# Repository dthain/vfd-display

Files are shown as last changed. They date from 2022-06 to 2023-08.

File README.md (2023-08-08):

# VFD Display Project

Some notes on building a display driver for a Futaba 16-LY-01ZL alphanumeric display.
It seems that Futaba no longer manufactures or supports these devices, but they are
commonly available for secondhand purchase.  The device has 37 pins at 0.2in spacing.

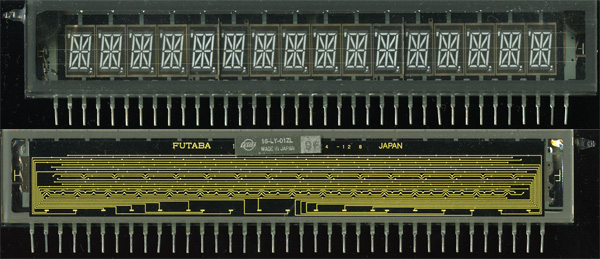
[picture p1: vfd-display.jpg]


This is a vacuum flourescent display (VFD), which is a variant of the vacuum tube.
A small AC current is used to heat a filament (cathode) when then produces electrons
via thermionic emission.  The electrons are naturally attracted to anodes, if they
are positively charged.  Each anode is coated with a flourescent material, and glows
a distinctive amber/green color when active.  Between the cathode and anode is a grid
that controls whether the electrons flow.

This particular one is a sixteen digit alphanumeric display.  Each digit has sixteen
segments, plus three more indicators: a dot in the upper left corner (Q) and
a decimal (R) and comma (S) in the lower right corner.  Each segment corresponds
to one anode, and each digit is controlled by a separate grid.  As a result, the
display can be multiplexed much like a multi-digit LED display.

```
.             S
 --- ---         HHH GGG
|\  |  /|       AI  N  LF
| \ | / |       A I N L F
 --- ---         PPP OOO
| / | \ |       B J M K E
|/  |  \|       BJ  M  KE
 --- ---         CCC DDD
         .               Q 
          /                R
```

## Datasheets and Testing

No datasheet is available for the device itself, however, it is mentioned in [this datasheet](datasheets/TDK-CD1867N.pdf) for DC/AC inverters,
which provides some key parameters:

|Converter | Ef r.m.s Vac | If (mAac) | V1 (Vdc) | V2 (Vdc) | I1 (mAdc) max. | I2 (mAdc) max. | Display |
|---|---|---|---|---|---|---|---|
|CD-1884N | 7.2 | 75 | -47 | -58 | 20.4 | 7.5 | 16-LY-01ZL |
|CD-1884P | 7.2 | 75 | 58 | - | 29.9 | -| 16-LY-01ZL |

There are two power supply variants here: the N variant sets both the cathode and anodes well below ground, while the P variant sets the cathode at ground (+/- the small AC voltage) and the anodes and grids at 58V.  Ef is the AC voltage applied to the filament to generate electrons, and V1 is the potential difference between cathode and anodes.

We can test the pinouts quickly by using some lower voltages that are easily available with components on hand.  Handily, the connections for the filament (either end) and grids are easily visible through the glass, while the anode connections are printed on the back of the device.  Test by applying 3.3V DC to the filament pins, and then using +30VDC to the grids and anodes to light up various segments:

Pin | Type | Number
---|---|---
1 | Filament | X 
2 | Anode | I
3 | Grid | 1
4 | Anode | S
5 | Grid | 2
6 | Anode | J
7 | Grid | 3
8 | Anode | K
9 | Grid | 4
10 | Anode | L
11 | Grid | 5
12 | Anode | M
13 | Anode | N
14 | Grid | 6
15 | Anode | O
16 | Grid | 7
17 | Anode | P
18 | Grid | 8
19 | Anode | Q
20 | Grid | 9
21 | Anode | R
22 | Grid | 10
23 | Anode | A
24 | Grid | 11
25 | Anode| B
26 | Anode | C
27 | Grid | 12
28 | Anode | D
29 | Grid | 13
30 | Anode | E
31 | Grid | 14
32 | Anode | F
33 | Grid | 15
34 | Anode | G
35 | Grid | 16
36 | Anode | H
37 | Filament | Y

## Block Diagram

There are 35 lines to be controlled.  If we leave out the dot, decimal, and comma,
then we need 32 GPIO lines in order to control 16 grids and 16 anodes.
The MCP23008 gives us eight I/O lines controllable via I2C,
and matches up nicely with an eight-way power driver (UDN2981) and eight-way
resistor bus that switches the 30V power.  Four of each of those can be stacked on an I2C bus as follows:

```
MCU -> I2C -> | -> MCP23008 => UDN2981 => Pulldowns => 8 Grids  (bank 0)
              | -> MCP23008 => UDN2981 => Pulldowns => 8 Anodes (bank 1)
              | -> MCP23008 => UDN2981 => Pulldowns => 8 Anodes (bank 2)
              | -> MCP23008 => UDN2981 => Pulldowns => 8 Grids  (bank 3)
                   /               ^
                  /                |
5V Power ----------> Boost -> 30V Power
                   Converter
```

## Circuit Board

[Fritzing PCB File](vfd-display-3.fzz)

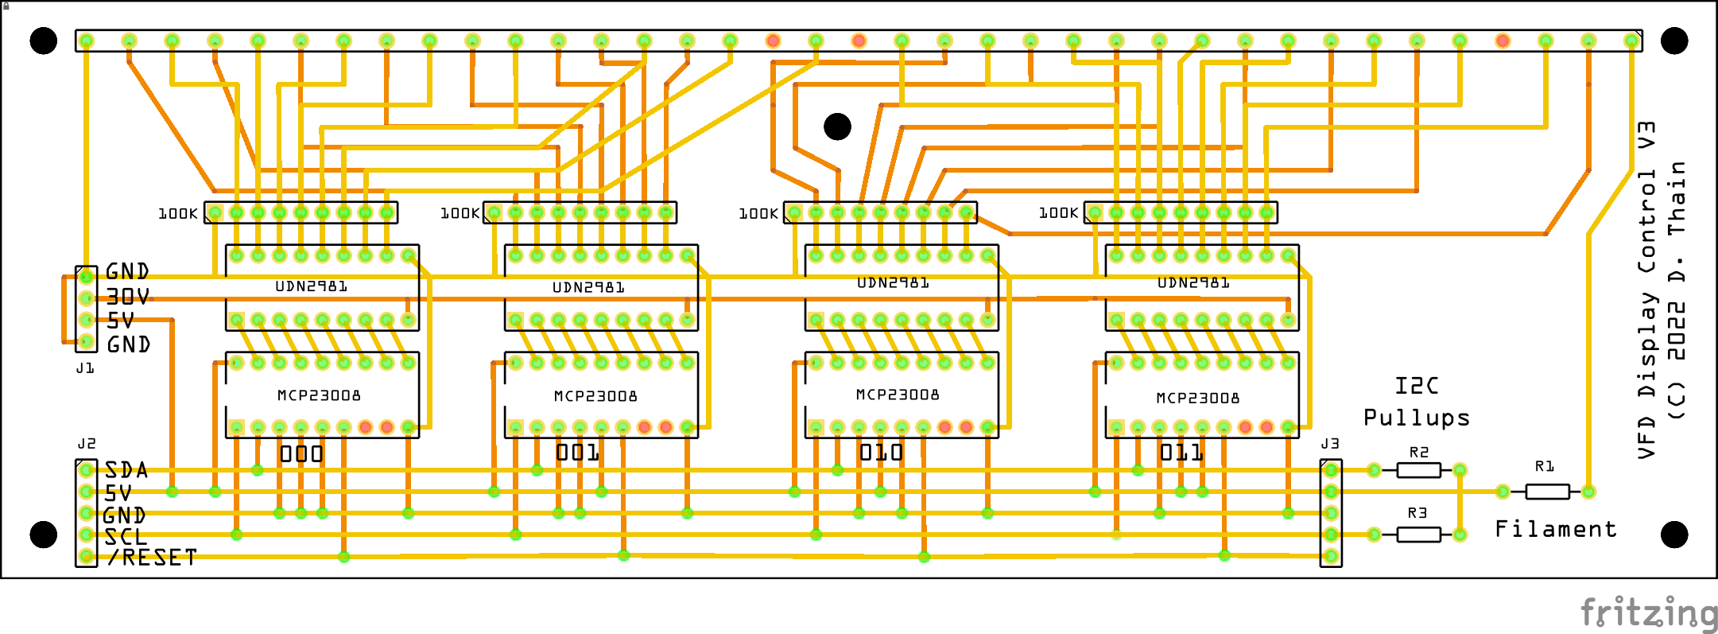
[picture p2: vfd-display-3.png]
Circuit Board


## Bill of Materials

| Quantity | Part | Description| Datasheet | Source
|---|---|---|---|---|
| 1 | 16-LY-01ZL | Futaba 16-Digit Alphanumeric  VFD | none | ebay
| 4 | UDN2981 | High-Side Power Drivers(x8) | [datasheet](datasheets/udn2981.pdf) | ebay
| 4 | MCP23008 | I2C I/O Expander (x8) | [datasheet](datasheets/mcp23008.pdf) | [digikey](https://www.digikey.com/en/products/detail/microchip-technology/MCP23008-E-P/735951)
| 4 | 4609X-AP1-103LF | 100K Resistor Array | | [digikey](https://www.digikey.com/en/products/detail/bourns-inc/4609X-101-104LF/3593673)
| 1 | | 5-35V Step-Up Power Module | | [amazon](https://www.amazon.com/DZS-Elec-Converter-Adjustable-Regulator/dp/B07L64GJ42)
| 1 | | Arduino Nano (or similar MCU) | | [amazon](gttps://www.amazon.com/Deegoo-ATmega328P-Microcontroller-Board-Arduino/dp/B07R9VWD39)
| 1 | | 15 Ohm, 1W Resistor | | (R1 filament driver)
| 2 | | 4.7K Ohm, 1/4W Resistor | | (R2/R3 I2C pullups)

## Build

Here is the board fresh from JLCPCB:

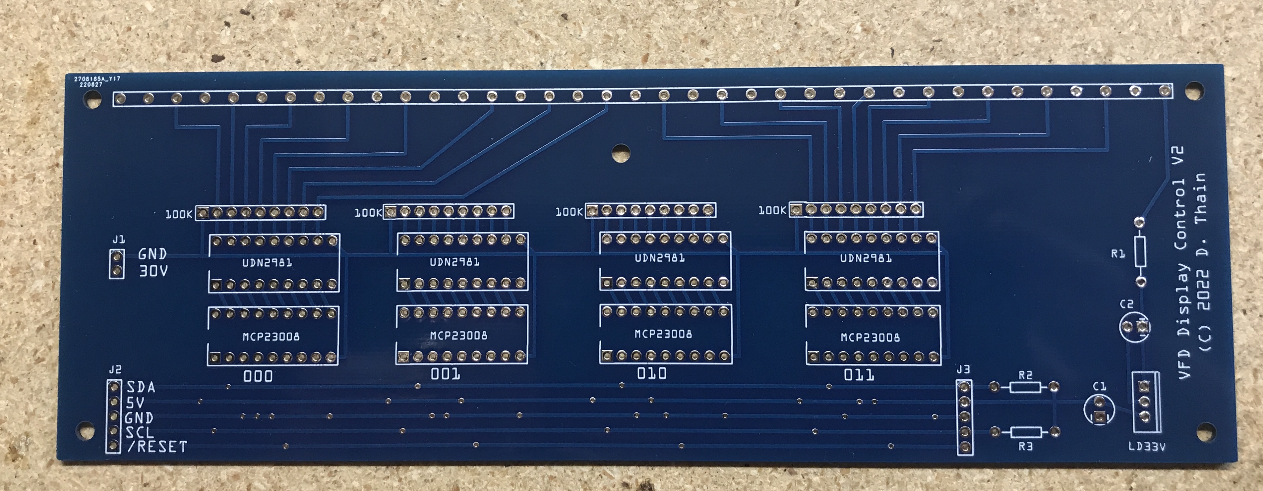
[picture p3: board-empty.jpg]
Finished Board


Here is the board populated with parts and the display.  (Note that the display faces away from the board.)

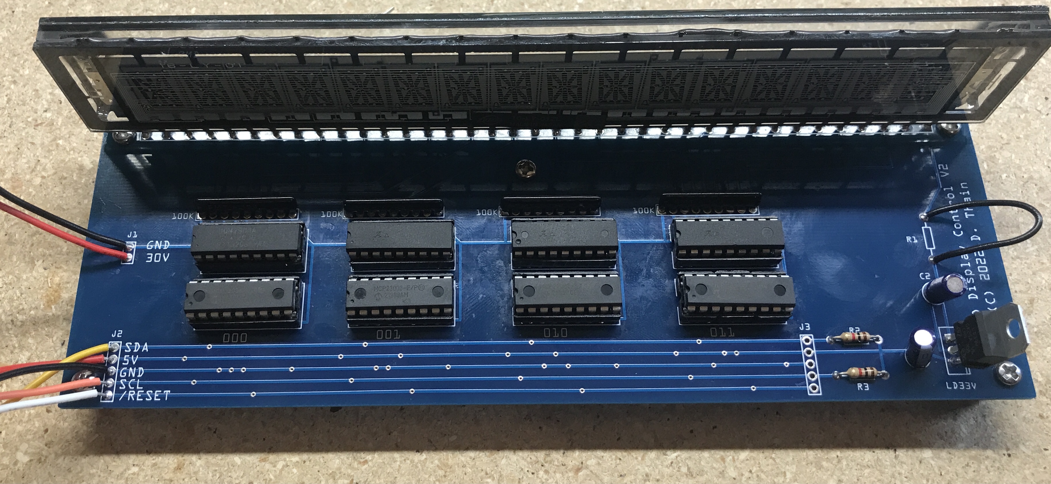
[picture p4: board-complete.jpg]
Populated Board


And here is the board powered up for the first time, showing all segments on.
Note that there is some variation in brightness across the digits.
This is because I am using DC across the filament, which results in some voltage
drop from one end to the other:

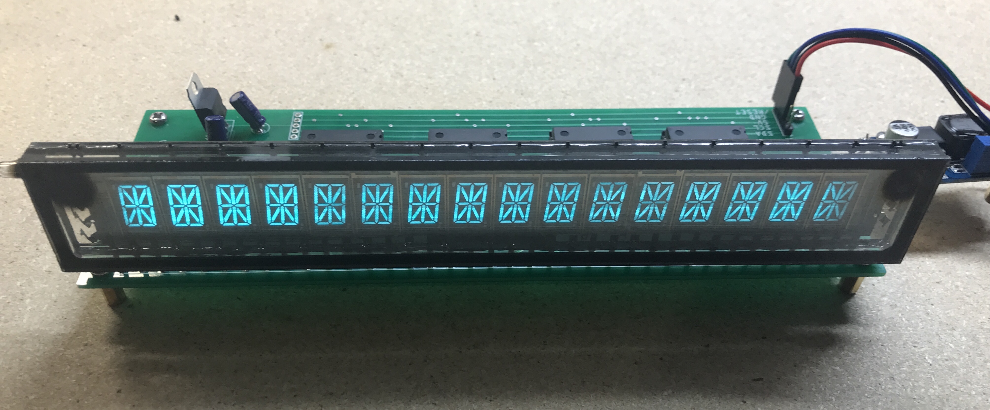
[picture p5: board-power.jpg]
Board Powered Up


## Principle of Operation

For the convenience of board layout, note that the MCP23008 outputs are in reverse
order from the transistor array, so we end up with the following correspondence between
output registers and display pins:

| Bank | I2C Addr | 7 | 6 | 5 | 4 | 3 | 2 | 1 | 0 |
|---|---|---|---|---|---|---|---|---|---|
| Bank 0 | 0x20 | G9 | G10 | G11 | G12 | G13 | G14 | G15 | G16 |
| Bank 1 | 0x21 | I | J | K | L | M | N | O | P |
| Bank 2 | 0x22 | A | B | C | D | E | F | G | H |
| Bank 3 | 0x23 | G1 | G2 | G3 | G4 | G5 | G6 | G7 | G8 |

To display a single character, we must send the appropriate bit pattern
to banks 1/2, and then enable one character by setting one bit low in
banks 0/4.  Each digit must be shown in turn at a rate of about 100Hz.

## Working Code

The following Arduino project [VFD-Display](Arduino/VFD-Display) puts this into action.
Briefly, the `MCP23008` module provides access to the four banks via I2C.
The `VFDController` module stores the 16-character array and transforms ASCII
into appropriate segments on the controller.  The `VFD-Display` main program
sets up the controller, and cycles through the digits.

As provided, it will display "YOUR NAME HERE" which you can replace with your own message.
If the Arduino remains connected to the serial port, you can write arbitrary ASCII lines
which will then be displayed.

I mounted the board and power supply on a piece of acrylic and use it as my office desk nameplate:

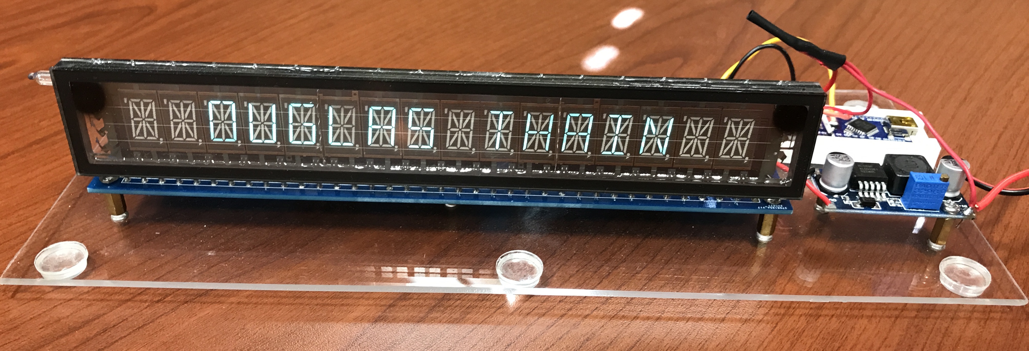
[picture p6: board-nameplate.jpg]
Office Nameplate


Because of the dynamic display, the photo doesn't quite capture all of the characters simulataneously, but it looks quite nice to the human eye.

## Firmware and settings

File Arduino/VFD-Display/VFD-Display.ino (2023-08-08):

/*
 * VFD Display Controller
 * Copyright (C) 2023 by Douglas Thain
 * This work is licensed under a Creative Commons Attribution 4.0 International License.
 * https://creativecommons.org/licenses/by/4.0/ 
 */
 
#include "Wire.h"
#include "VFDController.h"

VFDController control;

void setup()
{
  Wire.begin();

  // Set LED high briefly.
  pinMode(13,OUTPUT);
  digitalWrite(13,HIGH);
  
  // Hold display reset line low briefly.
  pinMode(3,OUTPUT);
  digitalWrite(3,LOW);
  delay(100);
  digitalWrite(3,HIGH);

  // Initialize the VFD display.
  control.begin();
  control.clear();

  // Wait one second before using the serial port,
  // to avoid difficulty with programming via bootloader.
  delay(1000);

  Serial.begin(9600);
  Serial.print("VFD Console Ready\n");

  control.write("YOUR NAME HERE\n");
  
  // LED back off to show reset complete.
  digitalWrite(13,LOW);
}

/*
 * In the main loop, rotate the next digit every 1ms.
 * If there is data available on the serial port, write it to the display.
 */

void loop()
{
  control.next_digit();
  while(Serial.available()) {
    char c = Serial.read();
    control.write(c);
  }
  delayMicroseconds(1);
}

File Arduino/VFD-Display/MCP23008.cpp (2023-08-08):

/*
 * VFD Display Controller
 * Copyright (C) 2023 by Douglas Thain 
 * This work is licensed under a Creative Commons Attribution 4.0 International License.
 * https://creativecommons.org/licenses/by/4.0/ 
 */

#include "MCP23008.h"

// I/O Direction 1=input, 0=output
#define MCP_IODIR 0x00

// Input Polarity, 0=normal 1=inverted
#define MCP_IPOL 0x01 

// Interrupt-on-change enable, 1=enable
#define MCP_GPINTEN 0x02

// Default comparison value for interrupt on change.
#define MCP_DEFVAL 0x03

// Interrupt control.  0=change 1=compare to DEFVAL.
#define MCP_INTCON 0x04

// I/O Configuration Register.
#define MCP_IOCON 0x05

// 100K Pull-ups on output pins: 1=enabled, 0=disabled
#define MCP_GPPU 0x06

// Interrupt flag register: 1=pin caused interrupt.
#define MCP_INTF 0x07

// Interrupt capture register: stores values from interruipt.
#define MCP_INTCAP 0x08

// GPIO register for read and write.
#define MCP_GPIO 0x09

// Output latch register.
#define MCP_OLAT 0x0A

#define MCP_IOCON_SEQP (1<<<5)  // 0 = sequential operation enabled
#define MCP_IOCON_DISSLW (1<<4) // 0 = slew rate enabled
#define MCP_IOCON_ODR (1<<2) // 1 = open-drain, 0=active driver
#define MCP_IOCON_INTPOL (1<<1) // 1 = INT pin active high, 0=active low

MCP23008::MCP23008()
{
}

void MCP23008::begin( uint8_t addr )
{
  i2c_addr = addr;
  set_direction(0);
  write(0);
}

void MCP23008::set_direction( uint8_t data )
{
  write_reg(MCP_IODIR,data);
}

uint8_t MCP23008::read()
{
  return read_reg(MCP_GPIO);
}

void MCP23008::write( uint8_t data, bool done )
{
  write_reg(MCP_GPIO,data,done);
}


void MCP23008::write_reg( int reg, uint8_t value, bool done )
{
  Wire.beginTransmission(i2c_addr);
  Wire.write(reg);
  Wire.write(value);
  Wire.endTransmission(done);
}

uint8_t MCP23008::read_reg( int reg )
{
  Wire.beginTransmission(i2c_addr);
  Wire.write(reg);
  Wire.endTransmission();
  
  Wire.requestFrom(i2c_addr,1);
  return Wire.read();
}

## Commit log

2022-06-21 Update BOM
2022-06-22 Add circuit board files.
    [vfd-display.fzz]
2022-09-19 Update to board version 2.
    [vfd-display.fzz]
2022-09-19 Update pin assignments.
2023-02-07 Update BOM for V3 board with power supply.
2023-02-07 Add V3 board files.
    [vfd-display-3.fzz]
2023-02-07 Updated image versions.
    [vfd-display.fzz]
2023-02-07 Fix errant label
    [vfd-display-3.fzz]
